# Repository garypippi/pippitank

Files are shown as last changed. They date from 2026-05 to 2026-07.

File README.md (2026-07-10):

# Pippitank

ラズパイ戦車制作プロジェクト

- 電源: 2S LiFe (タミヤ LF1100-6.6V)
- Raspberry Piでカメラ連携、リモート操作
- プッシュ型ソレノイドでBB弾発射

```
+----------+
| 2S LiFe  |
+----+-----+
     |
+----+-----------------+  UART  +-----------------------+
| pcb#pippitank-engine +--------+ pcb#pippitank-chassis |
+----+-----------------+        +----+--+-------+-------+
     |       |                       |  |       |
+-------+  +-------+      Dshot#2    |  |       | UART (Slip Ring)
| ESC#1 |  | ESC#2 |-----------------+  |       |
+----+--+  +-------+                    |    +----------------------+
     |                    Dshot#1       |    | pcb#pippitank-turret |
     +----------------------------------+    +----------------------+
                                                |
                                             ?? Planning... ??
```

## コマンド

### ビルド

```sh
cmake -S . -B build
cmake --build build
```

### RPi側

カメラストリーム配信。`--mode 1640:1232` はフル画角化のため（未指定だと中央クロップで約2.5倍ズームになる）:

```sh
rpicam-vid -t 0 --inline \
  --mode 1640:1232 \
  --width 640 --height 480 \
  --framerate 30 --listen -o tcp://0.0.0.0:8888
```

デーモン起動:

```sh
./build/src/pippitankd/pippitankd --listen 0.0.0.0:5000 --serial /dev/ttyS0
```

### ホスト側

操縦に使う入力デバイスの確認:

```sh
ls /dev/input/by-id
```

UI起動。`--log` は省略可（テレメトリCSVを記録する場合のみ）:

```sh
./build/src/pippitank-ui/pippitank-ui \
  --server pippitank:5000 \
  --video tcp://pippitank:8888 \
  --input /dev/input/event8 \
  --log logs/telemetry.csv
```

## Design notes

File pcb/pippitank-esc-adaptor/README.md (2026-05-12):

# ESCアダプタ基板

AM32 ESC(ARTERY AT32F421ベース、25A級) をシャーシに実装するためのアダプタ基板。
ESC × 2枚分で運用する。

## 目的

ESC本体を単独でシャーシに固定・配線するのが困難であるため、アダプタ基板に実装して機械・電気の一体化を図る。

## 全体構造

アダプタ基板の半月形状にし、内側2面でキャスタレーションする。
ESCを載せて実装。
各種コネクタ、バルクCの実装が容易になる想定。

追加パーツ:
定常5~15A、ピーク20~25A想定
ケーブルは18AWG

- コネクタ(電源): XT30PW-M
- コネクタ(出力): MR30PW-M
- コネクタ(信号): JST_XH_2PIN

銅箔はコスト、実用性の両面から、1oz。
両面にベタでstitching via。

電流容量検証(1oz 両面, 5mm幅相当):
- 連続容量 ≈ 14-16A(単層 8A の約2倍、2oz単層以上)
- 常用 5-15A、stall 瞬時 25A の要件に適合
- 発熱 0.16W@15A、温度上昇 10°C 未満

### バルクコンデンサ

ESCのBAT+/BAT-近傍に配置。
330μF、ESR性能重視。

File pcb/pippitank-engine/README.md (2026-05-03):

# pippitank-engine

2S Li-Po電源をESC#1, ESC#2, 車体システムへ分岐させる基板。

## 機能

- Pch-MOSFETで主電源ON/OFF
- MCUからNch-MOSFET経由でPch-MOSFETを制御
- 電圧監視
- 温度監視
- 電流監視

## 電圧監視地点

- 2S Li-Po電源 (VCC)
- 2S Li-Poセル#1 (バランスコネクタ経由)
- Pch-MOSFET直後

## 電流監視地点

各電源供給地点

- ESC#1
- ESC#2
- chassis/turret

## 温度測定地点

Pch-MOSFET近傍

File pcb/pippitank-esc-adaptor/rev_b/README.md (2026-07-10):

# pippitank-esc-adaptor rev_b

rev_a (2026-05-13 発注、2026-05-18 着) の実物検証で判明した課題を反映する次リビジョン。

**状態: 凍結 (2026-07-10)。rev_a が床走行まで実用に足りたため、着手トリガーは rev_a の故障・破損。**
本 README は着手時の申し送り集約として維持する。

## rev_a からの申し送り

### 1. Castellation スロット径拡大

rev_a は drill 0.6mm (JLCPCB 最小値) で設計、実物観察で側面銅露出が不足することが判明。

| Pad | 用途 | rev_a Size / Drill | rev_b 案 Size / Drill |
|---|---|---|---|
| 1, 2 | BAT+/BAT- | 3.0×2.5 / **0.6** | 3.0×2.5 / **1.0** |
| 3, 4, 5 | U/V/W 相出力 | 2.5×3.0 / **0.6** | 2.5×3.0 / **1.0** |
| 6, 7 | S/GND 信号 | 2.0×1.5 / **0.6** | 2.0×1.5 / **0.8** |

注: 寸法は JLCPCB castellation 仕様 (最小ピッチ・最小スロット径・推奨アスペクト比) を発注前に再確認すること。

### 2. QC 指標の変更

rev_a で「側面フィレット」を QC 指標としていたが、castellation の側面銅露出が
スロット内壁の半周のみであることが実物で確認された。形成不能なケースが標準となるため、
QC 指標として trivially に汚染される。

→ **rev_b 以降は「上面パッドのフィレット角度」を一次QC指標とする**。
   側面フィレットは形成されれば加点、未形成でも不合格にはしない。

### 3. U/V/W キャスタレーションのエッジカット中心ズレ

rev_a Known Issue より、U/V/W のエッジカットがスルーホール中心を通っていない。
rev_b で修正必須。

## 電流要件 (2026-06-26/27 床走行実測で確定)

rev_a 時代の仕様要求「常用 5-15A / ピーク 25A」は実測前の想定値だった。
床走行 Baseline (2S LiFe, 60:1 ウォーム, 超信地旋回・きびきび ramp 込み) の実測:

| 項目 | 実測値 |
|---|---|
| ESC 1台あたり DC 入力ピーク | **~3.5A** (きびきび ramp / 超信地旋回時) |
| 合計ピーク (2 ESC) | ~7A |
| 定常直進 | 1〜1.5A / ESC |
| 電圧サグ | 0.35V (系抵抗 ~78mΩ と整合、熱・電圧とも問題なし) |

**rev_b の設計電流は「各 ESC 10A」を採用** (engine rev_b 電流バジェット: 全体 30A = ESC 10A×2 + システム 10A と整合)。実測ピーク比で ~3倍のマージン。

### 注意 1: U/V/W 相電流は DC 入力より大きい

シャント実測は ESC の DC 入力側。相出力 (U/V/W) には duty < 100% で
DC 側より大きいトルク電流が流れる (一次近似 I_phase ≈ I_dc / duty)。
実測ピーク時 duty ~50% なら相側 ~7A 相当 → U/V/W パッドも 10A 基準で設計しておけば吸収できる。

### 注意 2: 個別ブランチの最悪ケース = 信地旋回は未測定

超信地旋回 (両履帯逆回転) はメイン電源パスの最悪ケースだが、片 ESC に旋回仕事が
集中する**信地旋回 (`l=±X, r=0`) は未取得**。片肺ピークが超信地の 1.5-1.6A/側を上回る
可能性はあるが、10A 設計に対して桁の余裕があるため設計ブロッカーではない。
詰める場合は信地旋回ログを別取りする。

## rev_a 許容電流試算 (参考、1oz Cu, IPC-2152 外層基準)

ボトルネックは上面パッド幅。バレル(半円メッキ)寄与は 2-3 割。

| 部位 | 連続容量 ΔT=10°C | 連続容量 ΔT=20°C |
|---|---|---|
| BAT± (3.0mm pad) | 11-12A | 15-17A |
| U/V/W (2.5mm pad) | 9-10A | 13-14A |

設計電流 10A に対し **rev_a 寸法のままでも ΔT=10°C 圏でほぼ収まる**。
したがって rev_b の drill 拡大 (0.6→1.0mm) の主目的は電流容量ではなく
**側面銅露出の改善 (はんだ濡れ性・QC 判定可能性) とマージン上積み**に整理される。
パッド拡大は必須ではなくなった (スペースと JLCPCB 制約次第の任意項目)。

## 設計タスク (TBD)

- [x] 電流要件の確定 (床走行実測 → 各 ESC 10A 基準、2026-07-10 反映)
- [ ] JLCPCB castellation 仕様再確認 (最小スロット径・ピッチ・縁部クリアランス)
- [ ] 上記寸法案で fp 修正・rev_a レイアウト引き継ぎ (パッド拡大は任意項目に格下げ)
- [ ] U/V/W エッジカット中心ズレ修正
- [ ] QC 指標の正式記載 (本 README 確定後、トップ README 反映)

## 注記

- 用途は室内床ホビー走行。屋外/泥/振動の脅威モデルは想定外
- 機械補強 (underfill, RTV 点付け, strain relief) は予防工程としては入れない。
  joint 浮きが出てから個別対処
- IPC-2152 ベースの試算は両面ベタGND+stitching via 構造で保守側、実機はやや余裕がある想定

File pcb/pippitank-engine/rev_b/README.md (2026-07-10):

改善

- FTDIモジュール対応
    - Arduino Unoのjtag2updi占有を脱する
- コネクタの最適化
    - 追記予定
- MCU駆動は3.3Vで統一

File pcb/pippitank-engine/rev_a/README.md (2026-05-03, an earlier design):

**Known Issues**

1. バランスコネクタのGND,8.4Vが逆
    - JST_XH_3PIN Verticalを逆で実装すること
2. Nch-MOSFETのソースが浮いている
    - SWはON状態で固定すること

## 主要パーツ

- MCU: ATtiny1604
- Pch-MOSFET: TJ60S04M3L
- 電流測定用アンプ: LT6106CS5

## 設計根拠

電力想定

- 各ESCはMAX30A
- システムはMAX5A

## コネクタ

- XT60PW-M: 2S Li-Po
- XT60PW-M: ESC#1
- XT60PW-M: ESC#2
- XT30PW-M: システム#1
- XT30PW-M: システム#2
- JST_XH_3PIN: 2S Li-Po バランスコネクタ
- JST_XH_3PIN: UPDI
- JST_XH_4PIN: UART

## 電流測定 (ESC)

シャント抵抗は1W7mΩ ±5%を調達
並列数は4、 上限30Aとして

- 各抵抗の電流: 7.5A
- 各抵抗の電力: 0.394W
- 電圧降下@30A: 52.5mV
- 必要利得    : 20.95
- 測定誤差@30A: ±0.2A
- 測定誤差@10A: ±2.0%
- 測定誤差@05A: ±4.0%

ADC基準電圧は、精度を優先し1.1Vを使用する。
必要利得は

20.95 = 1100 / 52.5

利得は`ROUT/RIN`で設定する。
RINの範囲にはLT6106内部電流の制約がある。

> 内部電流の上限は1mA、30A時のセンス電圧52.5mVを流すには
> RIN ≥ 52.5mV / 1mA = 52.5Ω
> が必要。
> データシート条件から
> RIN ≤ 500Ω

よって

52.5Ω < RIN < 500Ω

- RIN=240Ω
- ROUT=4.7kΩ (Av≈19.58)
- 出力@30A=1.028V
- 実効FS≈32.1A

出力フィルタは2段LPF構成にする。

- 1段目(LT6106付近): ROUT(4.7kΩ) × COUT1(0.1μF) ≈ 338Hz
    - PWMノイズ(16〜32kHz)を発生源で大幅減衰（-33dB以上）
    - フィルタ後の出力インピーダンスが高周波で低くなり、配線のアンテナ化を抑制
- 2段目(ADC付近): Rs(100Ω) × COUT2(10nF) ≈ 160kHz
    - 長配線で新規に拾ったHFスパイク（FETスイッチング過渡、RF誘導）を叩き落とす
    - ATtiny1604のSAR ADC S/Hキャパへのローカル電荷供給も兼用

```
┌───────┬───────┬──────────────────────────────────────┐
│ 素子  │  値   │                 用途                 │
├───────┼───────┼──────────────────────────────────────┤
│ RIN   │ 240Ω  │ 入力抵抗                             │
├───────┼───────┼──────────────────────────────────────┤
│ ROUT  │ 4.7kΩ │ 出力抵抗（利得設定 兼 1段目LPFのR）  │
├───────┼───────┼──────────────────────────────────────┤
│ COUT1 │ 0.1μF │ ROUT並列、1段目LPFのC（LT6106直近）  │
├───────┼───────┼──────────────────────────────────────┤
│ Rs    │ 100Ω  │ 2段目LPFの直列R（配線途中〜ADC直前） │
├───────┼───────┼──────────────────────────────────────┤
│ COUT2 │ 10nF  │ 2段目LPFのC（ADC直近）               │
└───────┴───────┴──────────────────────────────────────┘
```

**実装時はケルビン接続**

## 電流測定 (システム)

車体、砲塔への電流測定。
負荷はRPi Zero W、RPi Camera、サーボx2、プッシュ型ソレノイド、各MCU

シャント抵抗は1W40mΩ ±1%を調達
並列数は2、 上限5Aとして

- 各抵抗の電流: 2.5A
- 各抵抗の電力: 0.25W (定格50%デレーティング)
- 電圧降下@5A: 100mV
- 必要利得    : 11.0
- 測定誤差@5A: ±1.0%
- 測定誤差@1A: ±5.0%

ADC基準電圧は、精度を優先し1.1Vを使用する。
必要利得は

11.0 = 1100 / 100

- RIN=240Ω
- ROUT=2.4kΩ (Av≈10.0) ※ 2.4kΩは調達しやすい

出力フィルタは2段LPF構成にする。

- 1段目(LT6106付近): ROUT(2.4kΩ) × COUT1(0.1μF) ≈ 663Hz
- 2段目(ADC付近): Rs(100Ω) × COUT2(10nF) ≈ 160kHz

```
┌───────┬───────┬──────────────────────────────────────┐
│ 素子  │  値   │                 用途                 │
├───────┼───────┼──────────────────────────────────────┤
│ RIN   │ 240Ω  │ 入力抵抗                             │
├───────┼───────┼──────────────────────────────────────┤
│ ROUT  │ 2.4kΩ │ 出力抵抗（利得設定 兼 1段目LPFのR）  │
├───────┼───────┼──────────────────────────────────────┤
│ COUT1 │ 0.1μF │ ROUT並列、1段目LPFのC（LT6106直近）  │
├───────┼───────┼──────────────────────────────────────┤
│ Rs    │ 100Ω  │ 2段目LPFの直列R（配線途中〜ADC直前） │
├───────┼───────┼──────────────────────────────────────┤
│ COUT2 │ 10nF  │ 2段目LPFのC（ADC直近）               │
└───────┴───────┴──────────────────────────────────────┘
```

**実装時はケルビン接続**

## 電圧測定

測定地点

1. BATバランス端子: セル#1
2. BAT(+) - BAT(-): 2 - 1 = セル#2電圧
3. post-MOSFETノード - BAT(-): ESC両系統への給電電圧 (Pch-MOSFET ON確認 + 電圧降下モニタ兼用)

抵抗分圧について、精度優先で内蔵基準電圧1.1Vを使用する
MAX8.4として

- (R1+R2)/R2 = 8.4 / 1.1 = 7.64
- R1/R2 = 6.64

R1 = 67kΩ (47kΩ + 20kΩ)
R2 = 10kΩ (8.4V時 1.091V、6.0V時 0.779V)

MAX4.2の場合は R1=47kΩ にすれば良い(4.2V時 0.737V)

LT6106の電流測定と同じく、2段LPF構成で配置する

```
Vin ── R1 ──┬──[配線]── Rs ──┬── ATtiny ADC
            │                │
            R2               C2(10nF)
            │                │
            ├── C1(0.1μF)    GND
            │
           GND
```

- R1, R2, C1 は信号源側に密集させる
  - R2 をMCU側に離すと配線区間が R1=67kΩ の高インピーダンスになり、ノイズを盛大に拾う
  - R1||R2 = 8.7kΩ を信号源側で確立し、低インピーダンス信号を配線に乗せる
- Rs（100Ω）は配線途中〜ADC直前（LT6106と同規格）
  - 2段目LPFの直列R、ADC入力保護
- C2=10nF はADC直近（LT6106のCOUT2と共用規格）
  - 配線で拾ったHFノイズをADC直前でシャント
  - ATtiny1604 SAR ADC のS/Hキャパ充電にも寄与

```
┌───────┬──────────┬──────────────────────────────────────┐
│ 素子  │   値     │               用途                   │
├───────┼──────────┼──────────────────────────────────────┤
│ R1    │ 67kΩ等   │ 分圧上段（信号源側）                 │
├───────┼──────────┼──────────────────────────────────────┤
│ R2    │ 10kΩ     │ 分圧下段（信号源側、R1とセット）     │
├───────┼──────────┼──────────────────────────────────────┤
│ C1    │ 0.1μF    │ R2並列、1段目LPF（信号源側）         │
├───────┼──────────┼──────────────────────────────────────┤
│ Rs    │ 100Ω     │ 2段目LPFの直列R（電流系と共用規格）  │
├───────┼──────────┼──────────────────────────────────────┤
│ C2    │ 10nF     │ 2段目LPF（ADC直近、電流系と共用規格）│
└───────┴──────────┴──────────────────────────────────────┘
```

## 基板温度測定

Pch-MOSFET および シャント抵抗の発熱監視用に NTCサーミスタを1点実装する。

- サーミスタ: NTC 47kΩ ±5% B=4050K ±3% (TDK NTH5G20P40B473J、2012)
- プルアップ: 47kΩ ±5% (NTC R25と対称にして25°C付近の感度最大化、±5%は調達制約・表示用途なら実用上問題なし)
- フィルタ: 2段LPF構成
- ADC参照: VDD(5V) ※この1chのみ、他chは1.1V内部参照のまま

```
VCC(5V) ── R_pu 47kΩ ──┬──[配線]── Rs ──┬── ATtiny ADC (PA7)
                       │                │
                       NTC 47kΩ         C2 (10nF)
                       │                │
                       ├── C1 (0.1μF)   GND
                       │
                       GND
```

温度 vs ADCコード (VDD=5V, 10bit, B=4050K):

```
┌──────┬─────────┬────────┬─────────┐
│ 温度 │ NTC抵抗 │  電圧  │ ADCコード │
├──────┼─────────┼────────┼─────────┤
│ 0°C  │ 163kΩ   │ 3.88V  │  795    │
│ 25°C │ 47kΩ    │ 2.50V  │  512    │
│ 60°C │ 11.3kΩ  │ 0.97V  │  198    │
│ 85°C │ 4.84kΩ  │ 0.47V  │   96    │
│100°C │ 3.06kΩ  │ 0.31V  │   63    │
└──────┴─────────┴────────┴─────────┘
```

Pch-MOSFET裏面の銅箔ベタに密着させ、シャント抵抗発熱も熱結合で捕捉する。
シャットダウン閾値はマージンを取り ADCコード 110 (公称 82°C) 付近で発動、
最悪ケース (B+3%, R25+5%) でも実温度 85°C を超える前に遮断される想定とする。

```
┌───────┬──────────┬─────────────────────────────────────┐
│ 素子  │   値     │               用途                  │
├───────┼──────────┼─────────────────────────────────────┤
│ R_pu  │ 47kΩ ±5% │ プルアップ（信号源側）              │
├───────┼──────────┼─────────────────────────────────────┤
│ NTC   │ 47kΩ     │ NTH5G20P40B473J（信号源側）         │
├───────┼──────────┼─────────────────────────────────────┤
│ C1    │ 0.1μF    │ 1段目LPF（信号源側、NTC並列）       │
├───────┼──────────┼─────────────────────────────────────┤
│ Rs    │ 100Ω     │ 2段目LPFの直列R（全系統共用規格）   │
├───────┼──────────┼─────────────────────────────────────┤
│ C2    │ 10nF     │ 2段目LPF（ADC直近、全系統共用規格） │
└───────┴──────────┴─────────────────────────────────────┘
```

## ATtiny1604

ATtiny1604の消費電力は小さいので、BAT接続時は常に稼働させる

```
BAT(+) ---+---------- (VIN) AP7375 (VOUT) -+--- (A)▷|(K) --- VCC rail --- ATtiny1604
          |                  |             |         D2                   UPDI 5V pin
          | CIN=1μF          |             |
          |                  |             | COUT=10μF
BAT(-) ---+------------------+-------------+
```

- LDO: AP7375(5V300mA)
- 内蔵オシレータ使用
- UPDI引き出し
- 逆流防止ショットキー D2

BAT未接続状態でもArduino Uno経由でUPDI書き込みできるよう、AP7375出力とVCC rail間にショットキーダイオードを挿入する。

- 型番: RB160M-30TR (ROHM, 30V 1A)
- パッケージ: SOD-123F (PMDS、フラットリード)
- VF: 0.43V @ 1A、実動作の~10mA負荷では ~0.2V
- VCC rail電圧: 5.0V - 0.2V ≈ 4.8V（ATtiny動作範囲1.8-5.5V内）

```
AP7375 --+-- (A)▷|(K) ----+----- ATtiny VCC (pin 1)
         |      D2         |
         |                 +--- UPDI header 5V pin
         C2=10μF           |
         |                 C_bypass=0.1μF
        GND               GND
```

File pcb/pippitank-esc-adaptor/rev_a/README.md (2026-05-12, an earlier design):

**Known Issues**

1. U/V/Wのキャスタレーションでエッジカットがスルーホールの中心を通っていない

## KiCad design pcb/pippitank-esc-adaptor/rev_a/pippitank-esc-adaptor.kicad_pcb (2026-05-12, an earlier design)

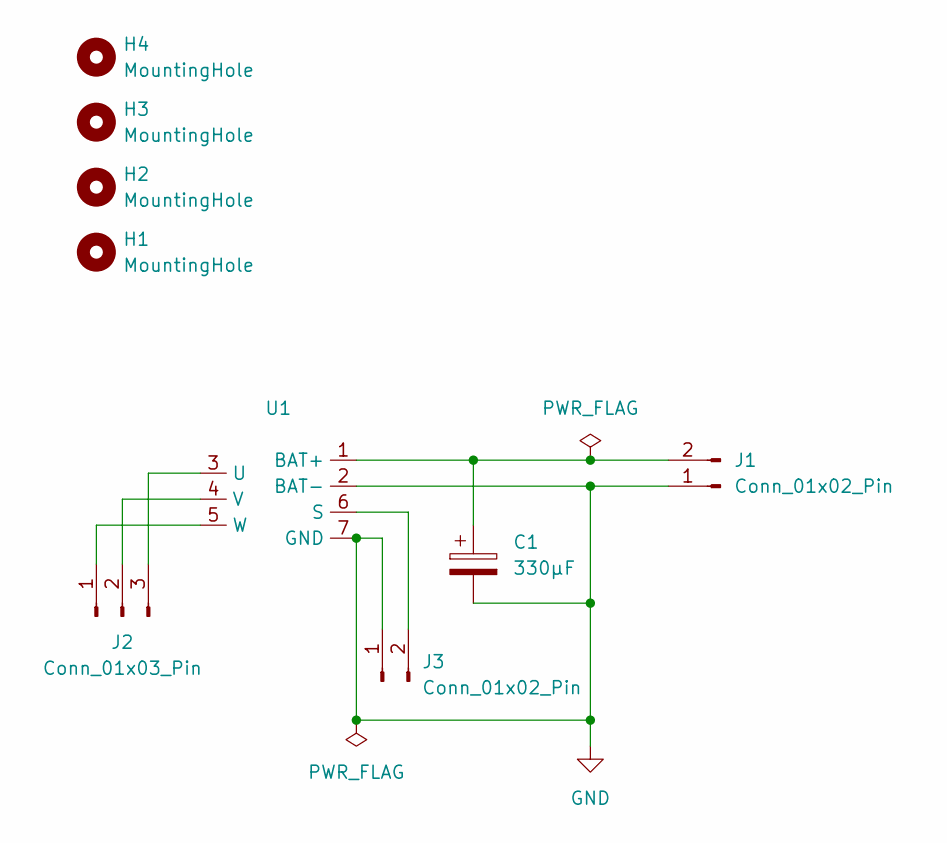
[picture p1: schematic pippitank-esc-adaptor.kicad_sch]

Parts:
C1: 330μF; CP_Radial_D10.0mm_P5.00mm
H1, H2, H3, H4: MountingHole; MountingHole_3.2mm_M3
J1: Conn_01x02_Pin; AMASS_XT30PW-M_1x02_P2.50mm_Horizontal
J2: Conn_01x03_Pin; AMASS_MR30PW-M_1x03_P3.50mm_Horizontal
J3: Conn_01x02_Pin; JST_XH_B2B-XH-A_1x02_P2.50mm_Vertical
U1: NOBRAND_ESC_ADAPTOR

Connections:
GND: C1.2, J1.1, J3.1, U1.2 (BAT-), U1.7 (GND)
unnamed: C1.1, J1.2, U1.1 (BAT+)
unnamed: J2.1, U1.5 (W)
unnamed: J2.2, U1.4 (V)
unnamed: J2.3, U1.3 (U)
unnamed: J3.2, U1.6 (S)

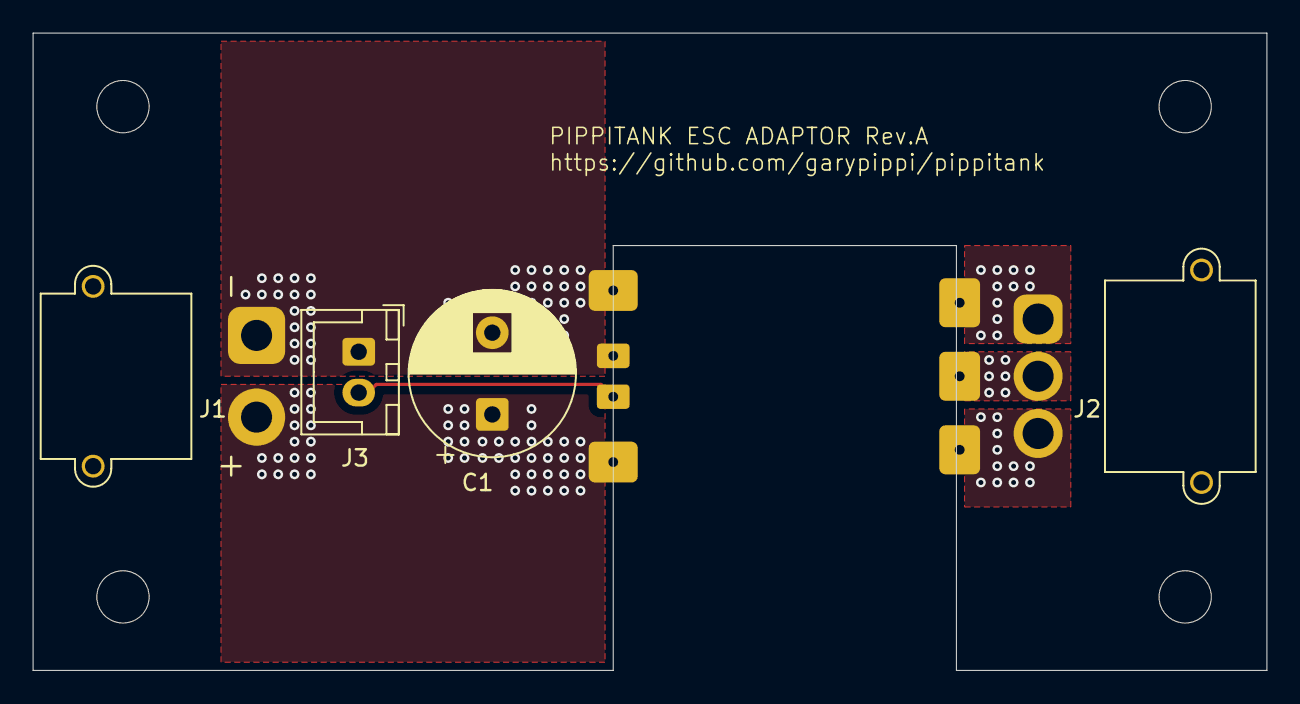
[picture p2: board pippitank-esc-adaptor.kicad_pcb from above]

Board: 2 copper layers, 75.5 x 39.0 mm, 9 parts (1 on the bottom side), 6 nets.

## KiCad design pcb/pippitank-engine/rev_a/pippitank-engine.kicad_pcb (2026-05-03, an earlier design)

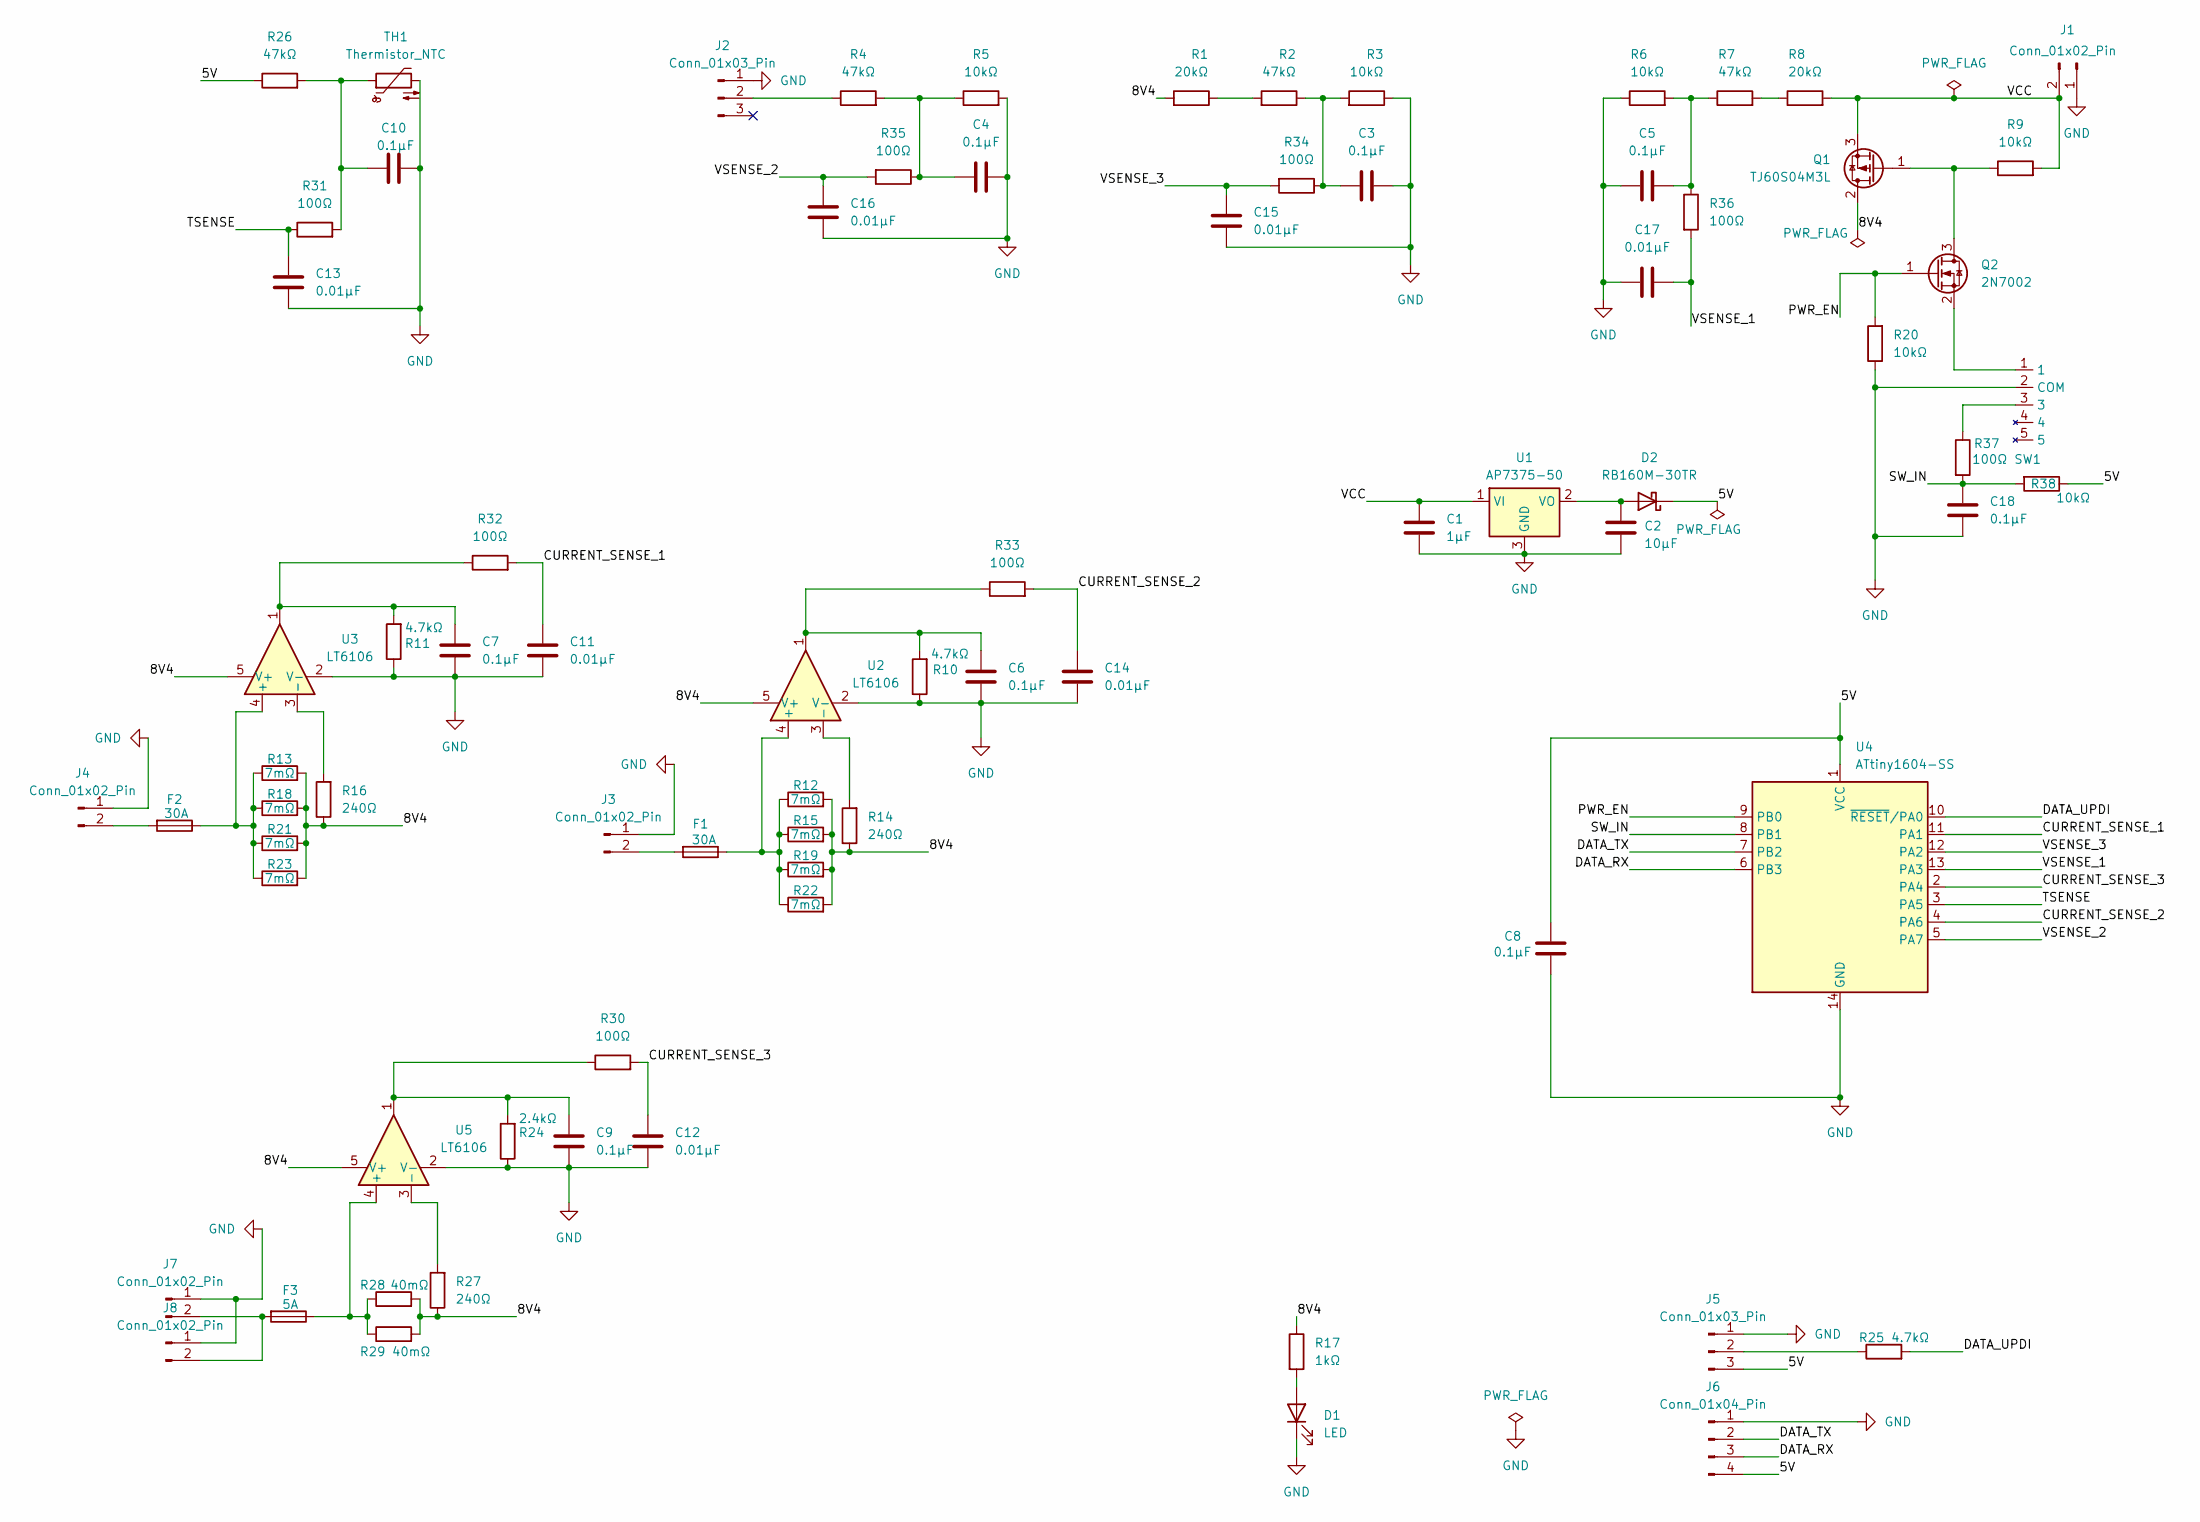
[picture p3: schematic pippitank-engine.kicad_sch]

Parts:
C1: 1μF; R_0603_1608Metric_Pad0.98x0.95mm_HandSolder
C2: 10μF; R_0805_2012Metric_Pad1.20x1.40mm_HandSolder
C3, C4, C5, C6, C7, C8, C9, C10, C18: 0.1μF; R_0603_1608Metric_Pad0.98x0.95mm_HandSolder
C11, C12, C13, C14, C15, C16, C17: 0.01μF; R_0603_1608Metric_Pad0.98x0.95mm_HandSolder
D1: LED; LED_0603_1608Metric_Pad1.05x0.95mm_HandSolder
D2: RB160M-30TR; D_SOD-123F
F1, F2: 30A; Keystone_3557_15
F3: 5A; Keystone_3557_15
J1, J3, J4: Conn_01x02_Pin; AMASS_XT60PW-M_1x02_P7.20mm_Horizontal
J2: Conn_01x03_Pin; JST_XH_S3B-XH-A_1x03_P2.50mm_Horizontal
J5: Conn_01x03_Pin; JST_XH_B3B-XH-A_1x03_P2.50mm_Vertical
J6: Conn_01x04_Pin; JST_XH_S4B-XH-A_1x04_P2.50mm_Horizontal
J7, J8: Conn_01x02_Pin; AMASS_XT30PW-M_1x02_P2.50mm_Horizontal
Q1: TJ60S04M3L; TO-252-3_TabPin2
Q2: 2N7002; SOT-23
R1, R8: 20kΩ; R_0603_1608Metric_Pad0.98x0.95mm_HandSolder
R2, R4, R7, R26: 47kΩ; R_0603_1608Metric_Pad0.98x0.95mm_HandSolder
R3, R5, R6, R9, R20, R38: 10kΩ; R_0603_1608Metric_Pad0.98x0.95mm_HandSolder
R10, R11, R25: 4.7kΩ; R_0603_1608Metric_Pad0.98x0.95mm_HandSolder
R12, R13, R15, R18, R19, R21, R22, R23: 7mΩ; R_2512_6332Metric
R14, R16, R27: 240Ω; R_0603_1608Metric_Pad0.98x0.95mm_HandSolder
R17: 1kΩ; R_0603_1608Metric_Pad0.98x0.95mm_HandSolder
R24: 2.4kΩ; R_0603_1608Metric_Pad0.98x0.95mm_HandSolder
R28, R29: 40mΩ; R_2512_6332Metric
R30, R31, R32, R33, R34, R35, R36, R37: 100Ω; R_0603_1608Metric_Pad0.98x0.95mm_HandSolder
SW1: SSAJ120100
TH1: Thermistor_NTC; R_0805_2012Metric_Pad1.20x1.40mm_HandSolder
U1: AP7375-50; SOT-23_Handsoldering
U2, U3, U5: LT6106; SOT-23-5_HandSoldering
U4: ATtiny1604-SS; SOIC-14_3.9x8.7mm_P1.27mm

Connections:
/5V: C8.2, D2.1 (K), J5.3, J6.4, R26.1, R38.1, U4.1 (VCC)
/8V4: Q1.2 (D), R1.2, R12.2, R13.2, R14.1, R15.2, R16.1, R17.1, R18.2, R19.2, R21.2, R22.2, R23.2, R27.1, R28.2, R29.2, U2.5 (V+), U3.5 (V+), U5.5 (V+)
/CURRENT_SENSE_1: C11.1, R32.2, U4.11 (PA1)
/CURRENT_SENSE_2: C14.1, R33.2, U4.4 (PA6)
/CURRENT_SENSE_3: C12.1, R30.2, U4.2 (PA4)
/DATA_RX: J6.3, U4.6 (PB3)
/DATA_TX: J6.2, U4.7 (PB2)
/DATA_UPDI: R25.2, U4.10 (~RESET/PA0)
/PWR_EN: Q2.1 (G), R20.2, U4.9 (PB0)
/SW_IN: C18.2, R37.2, R38.2, U4.8 (PB1)
/TSENSE: C13.1, R31.1, U4.3 (PA5)
/VCC: C1.1, J1.2, Q1.3 (S), R8.2, R9.2, U1.1 (VI)
/VSENSE_1: C17.1, R36.2, U4.13 (PA3)
/VSENSE_2: C16.2, R35.2, U4.5 (PA7)
/VSENSE_3: C15.2, R34.2, U4.12 (PA2)
GND: C1.2, C2.2, C3.2, C4.2, C5.2, C6.2, C7.2, C8.1, C9.2, C10.1, C11.2, C12.2, C13.2, C14.2, C15.1, C16.1, C17.2, C18.1, D1.1 (K), J1.1, J2.1, J3.1, J4.1, J5.1, J6.1, J7.1, J8.1, R3.1, R5.2, R6.1, R10.1, R11.1, R20.1, R24.1, SW1.2 (COM), TH1.2, U1.3 (GND), U2.2 (V-), U3.2 (V-), U4.14 (GND), U5.2 (V-)
unnamed: C3.1, R2.1, R3.2, R34.1
unnamed: C4.1, R4.2, R5.1, R35.1
unnamed: C5.1, R6.2, R7.1, R36.1
unnamed: C6.1, R10.2, R33.1, U2.1
unnamed: C7.1, R11.2, R32.1, U3.1
unnamed: C9.1, R24.2, R30.1, U5.1
unnamed: C10.2, R26.2, R31.2, TH1.1
unnamed: D1.2 (A), R17.2
unnamed: C2.1, D2.2 (A), U1.2 (VO)
unnamed: J2.2, R4.1
unnamed: F1.2, J3.2
unnamed: F2.2, J4.2
unnamed: J5.2, R25.1
unnamed: F3.2, J7.2, J8.2
unnamed: Q1.1 (G), Q2.3 (D), R9.1
unnamed: Q2.2 (S), SW1.1
unnamed: R1.1, R2.2
unnamed: R7.2, R8.1
unnamed: R37.1, SW1.3
unnamed: F1.1, R12.1, R15.1, R19.1, R22.1, U2.4 (+)
unnamed: R14.2, U2.3 (-)
unnamed: F2.1, R13.1, R18.1, R21.1, R23.1, U3.4 (+)
unnamed: R16.2, U3.3 (-)
unnamed: F3.1, R28.1, R29.1, U5.4 (+)
unnamed: R27.2, U5.3 (-)

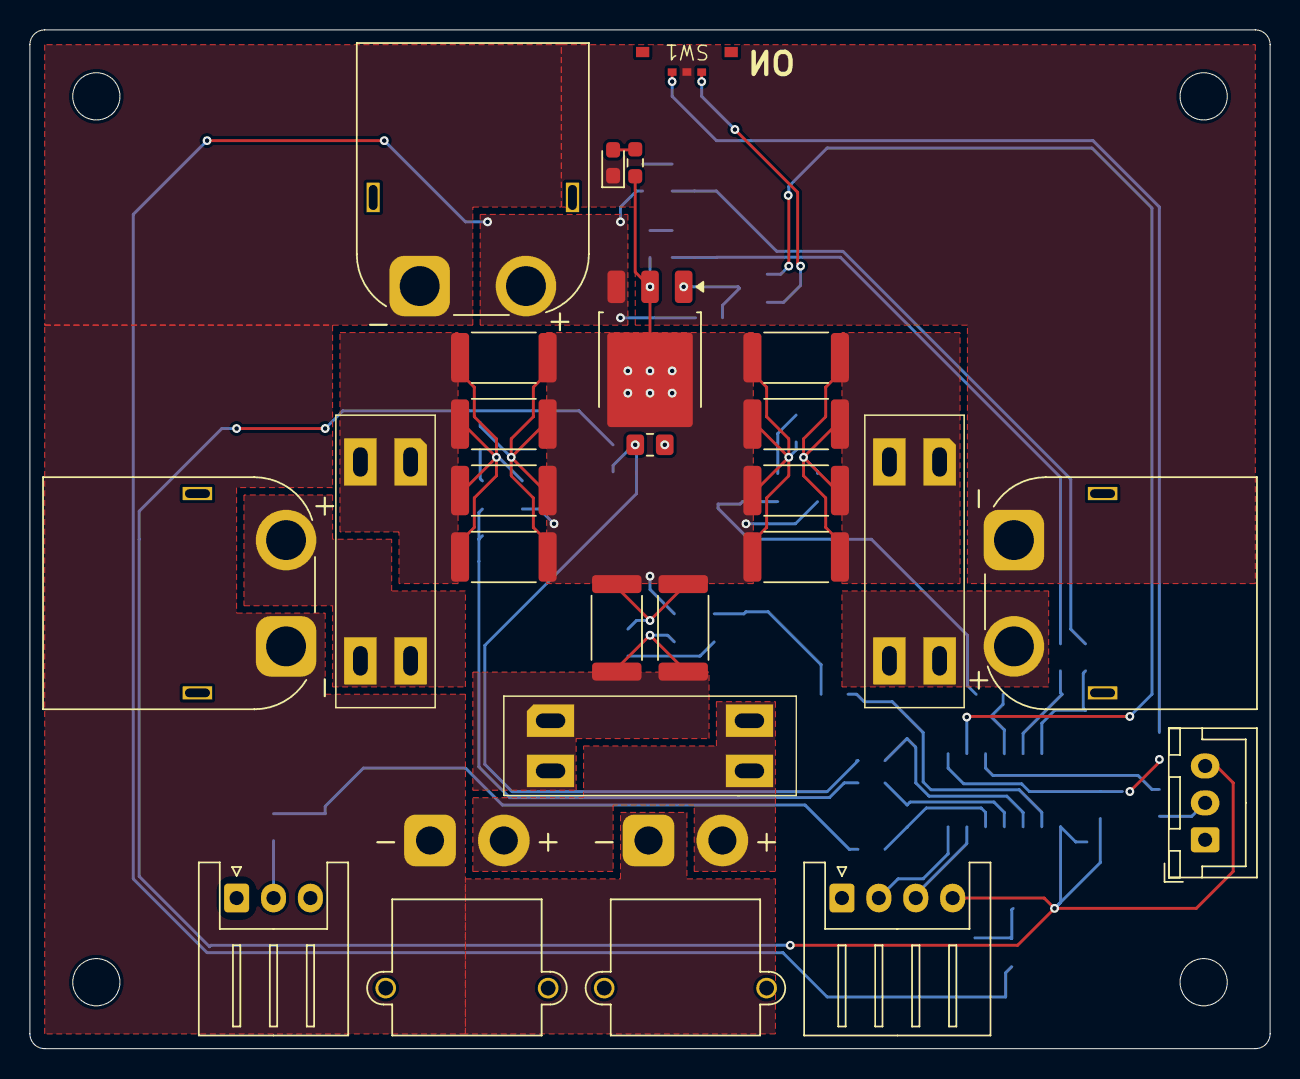
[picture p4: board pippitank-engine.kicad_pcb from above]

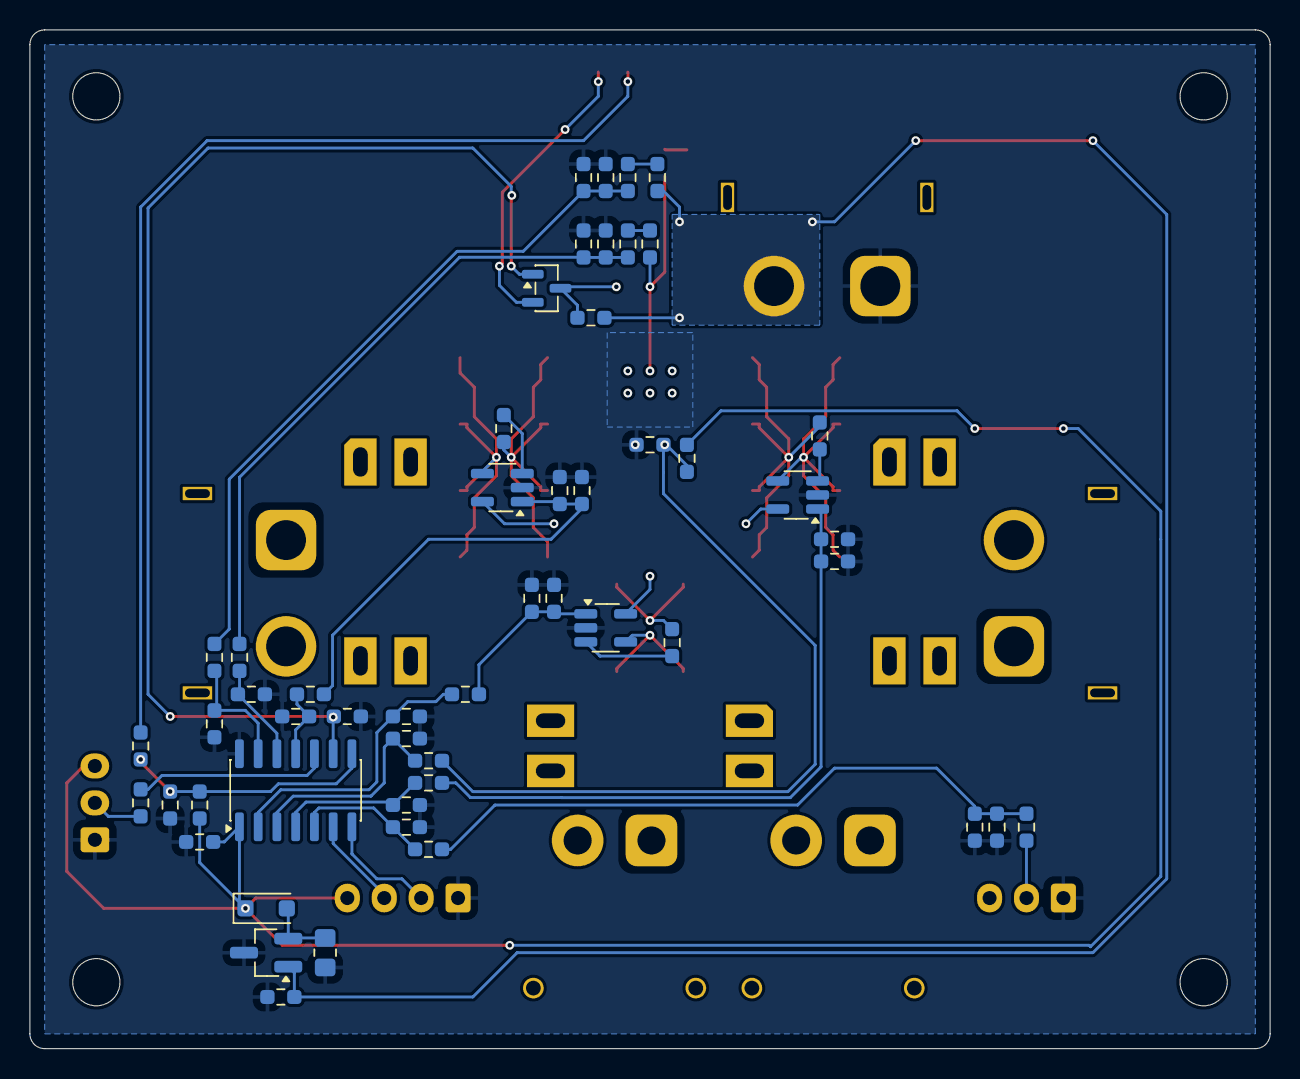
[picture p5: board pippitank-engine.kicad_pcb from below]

Board: 2 copper layers, 84.0 x 69.0 mm, 78 parts (52 on the bottom side), 41 nets.

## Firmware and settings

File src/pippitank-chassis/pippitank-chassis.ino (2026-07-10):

//const uint32_t BAUDRATE = 19200;
//uint32_t hb_last_ms = 0;
//uint32_t hb_state   = false;
//
//void setup() {
//  // RPi
//  Serial1.setTX(0);
//  Serial1.setRX(1);
//  Serial1.begin(BAUDRATE);
//
//  // pippitank-engine
//  Serial2.setTX(4);
//  Serial2.setRX(5);
//  Serial2.begin(BAUDRATE);
//  //Serial1.begin(BAUDRATE); // RPi
//  //Serial2.begin(BAUDRATE); // pippitank-engine
//  pinMode(LED_BUILTIN, OUTPUT);
//}
//
//void loop() {
//  // Pass through pippitank-engine's telemetory
//  if (Serial2.available()) {
//    Serial1.write(Serial2.read());
//  }
//
//  // Heart beat
//  uint32_t now = millis();
//  if (now - hb_last_ms >= 500) {
//    hb_last_ms = now;
//    hb_state = !hb_state;
//    digitalWrite(LED_BUILTIN, hb_state);
//  }
//}


#include <Servo.h>
#include "./protocol.h"

const uint8_t PIN_ESC_1 = 6;   // 適宜
const uint8_t PIN_ESC_2 = 7;

const int PWM_MIN  = 1000;
const int PWM_MAX  = 2000;
const int PWM_IDLE = 1500;

Servo esc_l;
Servo esc_r;

const uint32_t BAUDRATE = 19200;
const uint8_t  LED_PIN  = LED_BUILTIN;

uint32_t led_last_ms  = 0;
uint32_t stat_last_ms = 0;
bool     led_state    = false;

uint32_t engine_frames_ok  = 0;
uint32_t engine_frames_err = 0;

struct pt_rx rx_engine;
struct pt_rx rx_cmd;

const uint32_t ESC_ARM_DELAY_MS = 2000;
bool esc_armed = false;

const uint32_t CHASSIS_TX_PERIOD_MS = 33;   // 30Hz
uint32_t chassis_tx_last_ms = 0;

volatile int16_t  target_throttle_l = 0;
volatile int16_t  target_throttle_r = 0;
volatile uint32_t last_cmd_ms       = 0;

const uint32_t ESC_UPDATE_MS = 20;   // 50Hz
const uint32_t CMD_TIMEOUT_MS = 500;
uint32_t esc_update_last = 0;

//void handle_cmd(const struct pt_rx *rx) {
//    const struct pt_header *hdr = (const struct pt_header *)rx->buf;
//    if (hdr->typ == PT_TYP_CMD_DRIVE
//        && hdr->len == sizeof(struct pt_payload_cmd_drive)) {
//        const struct pt_frame_cmd_drive *f = (const struct pt_frame_cmd_drive *)rx->buf;
//        target_throttle_l = f->payload.throttle_l;
//        target_throttle_r = f->payload.throttle_r;
//        last_cmd_ms = millis();
//          Serial.printf("CMD_DRIVE L=%d R=%d (count=%u)\n",
//                last_throttle_l, last_throttle_r, cmd_count);
//    }
//}
uint32_t cmd_count = 0;
//int16_t  last_throttle_l = 0;
//int16_t  last_throttle_r = 0;
void handle_cmd(const struct pt_rx *rx) {
  const struct pt_header *hdr = (const struct pt_header *)rx->buf;

  if (hdr->typ == PT_TYP_CMD_DRIVE
      && hdr->len == sizeof(struct pt_payload_cmd_drive))
  {
      const struct pt_frame_cmd_drive *f = (const struct pt_frame_cmd_drive *)rx->buf;
      target_throttle_l = f->payload.throttle_l;
      target_throttle_r = f->payload.throttle_r;
      last_cmd_ms = millis();
      cmd_count++;
      Serial.printf("CMD_DRIVE L=%d R=%d (count=%u)\n",
                    target_throttle_l, target_throttle_r, cmd_count);
  }
}

void send_chassis_telemetry() {
     struct pt_frame_chassis frame;
     frame.header.syn = PT_SYNC;
     frame.header.src = PT_SRC_CHASSIS;
     frame.header.typ = PT_TYP_TELEMETORY;
     frame.header.len = sizeof(frame.payload);

     frame.payload.uptime_ms = millis();
     frame.payload.engine_frames_ok = engine_frames_ok;
     frame.payload.engine_frames_dropped = 0;   // 実装は後で
     frame.payload.flags = 0;

     frame.crc = pt_crc8(&frame.header.src, 3 + sizeof(frame.payload));

     Serial1.write((const uint8_t*)&frame, sizeof(frame));
}

int throttle_to_pwm(int16_t t) {
      if (t > 1000)  t = 1000;
      if (t < -1000) t = -1000;
      return PWM_IDLE + t / 2;   // -1000 → 1000us, 0 → 1500us, +1000 → 2000us
}

void setup() {
    Serial.begin(115200);

    Serial1.setTX(0);
    Serial1.setRX(1);
    Serial1.begin(BAUDRATE);

    Serial2.setTX(4);
    Serial2.setRX(5);
    Serial2.begin(BAUDRATE);

    pinMode(LED_PIN, OUTPUT);

    esc_l.attach(PIN_ESC_1, PWM_MIN, PWM_MAX);
    esc_r.attach(PIN_ESC_2, PWM_MIN, PWM_MAX);
    esc_l.writeMicroseconds(PWM_IDLE);
    esc_r.writeMicroseconds(PWM_IDLE);

    pt_rx_init(&rx_engine);
}

void loop() {
    // engine からの受信 → state machine へ
    while (Serial2.available()) {
        uint8_t b = Serial2.read();
        pt_rx_feed(&rx_engine, b);

        if (rx_engine.done == 1) {
            rx_engine.done = 0;
            // フレーム完成 → そのまま RPi へ
            // 全長 = sizeof(pt_header) + payload_len + 1(CRC)
            size_t frame_len = sizeof(struct pt_header) + rx_engine.buf[3] + 1;
            Serial1.write(rx_engine.buf, frame_len);
            engine_frames_ok++;
        }
        // CRC エラーは pt_rx_feed 内で done=0 のまま捨てられる
        // → ここでは err カウントできない、要なら state machine 側に追加
    }

    while (Serial1.available()) {
        uint8_t b = Serial1.read();
        pt_rx_feed(&rx_cmd, b);
        if (rx_cmd.done == 1) {
            rx_cmd.done = 0;
            handle_cmd(&rx_cmd);
        }
    }

    uint32_t now = millis();

    // chassis 自前テレメトリ
    if (now - chassis_tx_last_ms >= CHASSIS_TX_PERIOD_MS) {
        chassis_tx_last_ms = now;
        send_chassis_telemetry();
    }

    if (!esc_armed && now >= ESC_ARM_DELAY_MS) {
        esc_armed = true;
    }

    if (now - last_cmd_ms > CMD_TIMEOUT_MS) {
      target_throttle_l = 0;
      target_throttle_r = 0;
    }

    if (now - esc_update_last >= ESC_UPDATE_MS) {
         esc_update_last = now;
         if (esc_armed) {
             Serial.printf("ESC %d %d \n", throttle_to_pwm(target_throttle_l), throttle_to_pwm(target_throttle_r));
             esc_l.writeMicroseconds(throttle_to_pwm(target_throttle_l));
             esc_r.writeMicroseconds(throttle_to_pwm(target_throttle_r));
         }
    }

    // ハートビート LED
    if (now - led_last_ms >= 500) {
        led_last_ms = now;
        led_state = !led_state;
        digitalWrite(LED_PIN, led_state);
    }
    // 統計
    if (now - stat_last_ms >= 1000) {
        stat_last_ms = now;
        Serial.printf("engine_ok=%u\n", engine_frames_ok);
    }
}

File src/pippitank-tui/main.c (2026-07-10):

#include "../protocol.h"
#include "./conv.h"
#include <arpa/inet.h>
#include <fcntl.h>
#include <getopt.h>
#include <linux/input.h>
#include <ncurses.h>
#include <netinet/in.h>
#include <poll.h>
#include <signal.h>
#include <stdio.h>
#include <stdlib.h>
#include <sys/socket.h>
#include <sys/timerfd.h>
#include <sys/un.h>
#include <unistd.h>

#define BUFFER_SIZE 128

// enum pt_rx_state {
//     WAIT_SYNC,
//     READ_HEADER,
//     READ_PAYLOAD,
//     READ_CRC
// };
//
// struct pt_rx_engine {
//     enum pt_rx_state state;
//     uint8_t buf[sizeof(struct pt_frame_engine) + 1];
//     uint16_t pos;
//     uint16_t len;
//     int done;
// };

void cleanup_ncurses(void) { endwin(); }

void on_sigint(int sig) {
  (void)sig;
  exit(0);
}

// y, x: 描画開始位置、width: バー幅(文字数)、value: 値、max: 最大値
void draw_bar(int y, int x, int width, float value, float max) {
  if (value < 0)
    value = 0;
  if (value > max)
    value = max;
  int filled = (int)(value * width / max);

  mvaddch(y, x, '[');
  for (int i = 0; i < width; i++) {
    mvaddch(y, x + 1 + i, i < filled ? '#' : '.');
  }
  mvaddch(y, x + 1 + width, ']');
}

// void pt_rx_engine_feed(struct pt_rx_engine* engine, uint8_t data)
//{
//     switch (engine->state)
//     {
//         case WAIT_SYNC:
//             if (data == PT_SYNC)
//             {
//                 engine->state = READ_HEADER;
//                 engine->buf[engine->pos++] = data;
//                 engine->len = sizeof(struct pt_header) - 1;
//             }
//             break;
//         case READ_HEADER:
//             engine->buf[engine->pos++] = data;
//             engine->len--;
//
//             if (engine->len == 0)
//             {
//                 engine->state = READ_PAYLOAD;
//                 engine->len = sizeof(struct pt_payload_engine);
//                 if (engine->buf[3] != sizeof(struct pt_payload_engine))
//                 {
//                     fprintf(stderr, "[ERROR] pt_header len mismatch.\n");
//                     engine->state = WAIT_SYNC;
//                     engine->pos = 0;
//                 }
//             }
//             break;
//         case READ_PAYLOAD:
//             engine->buf[engine->pos++] = data;
//             engine->len--;
//
//             if (engine->len == 0)
//             {
//                 engine->state = READ_CRC;
//             }
//             break;
//         case READ_CRC:
//             if (pt_crc8(engine->buf + 1, 3 + sizeof(struct
//             pt_payload_engine)) != data)
//             {
//                 fprintf(stderr, "[ERROR] CRC error\n");
//             }
//             else
//             {
//                 engine->done = 1;
//             }
//             engine->buf[engine->pos] = data;
//             engine->state = WAIT_SYNC;
//             engine->pos = 0;
//             break;
//     }
// }

struct app_state {
  struct pt_payload_engine engine_latest;
  bool engine_valid;
  struct pt_payload_chassis chassis_latest;
  bool chassis_valid;
  uint32_t engine_frame_count;
  uint32_t chassis_frame_count;
};

void render(const struct app_state *s) {
  erase();

  if (s->engine_valid) {
    const struct pt_payload_engine *e = &s->engine_latest;
    mvprintw(0, 0, "ENGINE  uptime %.1f s frames %u", e->uptime_ms / 1000.0f,
             s->engine_frame_count);

    mvprintw(2, 0, "V_BAT     %5.2f V", adc_to_v_bat(e->adc_v_cell_2));
    draw_bar(2, 24, 30, adc_to_v_bat(e->adc_v_cell_2), 8.4f);

    mvprintw(3, 0, "V_CELL1   %5.2f V", adc_to_v_cell1(e->adc_v_cell_1));
    draw_bar(3, 24, 30, adc_to_v_cell1(e->adc_v_cell_1), 4.2f);

    mvprintw(4, 0, "V_Q       %5.2f V", adc_to_v_q(e->adc_v_q));
    draw_bar(4, 24, 30, adc_to_v_q(e->adc_v_q), 8.4f);

    mvprintw(6, 0, "I_ESC1    %6.2f A", adc_to_i_esc(e->adc_i_esc_1));
    draw_bar(6, 24, 30, adc_to_i_esc(e->adc_i_esc_1), 30.0f);

    mvprintw(7, 0, "I_ESC2    %6.2f A", adc_to_i_esc(e->adc_i_esc_2));
    draw_bar(7, 24, 30, adc_to_i_esc(e->adc_i_esc_2), 30.0f);

    mvprintw(8, 0, "I_SYS     %6.2f A", adc_to_i_sys(e->adc_i_sys));
    draw_bar(8, 24, 30, adc_to_i_sys(e->adc_i_sys), 5.0f);

    mvprintw(10, 0, "TEMP     %5.1f C", adc_to_temp_c(e->adc_temp));
    draw_bar(10, 24, 30, adc_to_temp_c(e->adc_temp), 100.0f);
    // mvprintw(0, 0, "ENGINE  uptime %.1f s   frames %u",
    //          e->uptime_ms / 1000.0f, s->engine_frame_count);
    // mvprintw(2, 0, "V_BAT     %5.2f V", adc_to_v_bat(e->adc_v_cell_2));
    // draw_bar(2, 24, 30, adc_to_v_bat(e->adc_v_cell_2), 8.4f);
    //  ... 既存表示 ...
  } else {
    mvprintw(0, 0, "ENGINE  waiting...");
  }

  if (s->chassis_valid) {
    const struct pt_payload_chassis *c = &s->chassis_latest;
    mvprintw(13, 0, "CHASSIS uptime %.1f s   frames %u", c->uptime_ms / 1000.0f,
             s->chassis_frame_count);
    mvprintw(14, 0, "  engine_ok=%u  drop=%u  flags=0x%02X",
             c->engine_frames_ok, c->engine_frames_dropped, c->flags);
  } else {
    mvprintw(13, 0, "CHASSIS waiting...");
  }

  refresh();
}

struct keys {
  bool w, a, s, d;
};

float current_throttle_fwd = 0.0f;  // 前後 (-1000..+1000)
float current_throttle_turn = 0.0f; // 左右

const float RAMP_PER_TICK_FWD = 2.5f; // 50Hz × 50 = 2500/s → 0.4s で full
const float RAMP_PER_TICK_TURN = 2.5f;
const float DECAY_PER_TICK = 2.5f; // 解放時の戻り

void compute_target_and_ramp(const struct keys *k, int16_t *out_l,
                             int16_t *out_r) {
  // 目標値
  float target_fwd = 0.0f;
  if (k->w)
    target_fwd += 1000.0f;
  if (k->s)
    target_fwd -= 1000.0f;
  float target_turn = 0.0f;
  if (k->d)
    target_turn += 1000.0f;
  if (k->a)
    target_turn -= 1000.0f;

  // 前後ramp
  float diff_fwd = target_fwd - current_throttle_fwd;
  float step_fwd = (target_fwd != 0.0f) ? RAMP_PER_TICK_FWD : DECAY_PER_TICK;
  if (diff_fwd > step_fwd)
    current_throttle_fwd += step_fwd;
  else if (diff_fwd < -step_fwd)
    current_throttle_fwd -= step_fwd;
  else
    current_throttle_fwd = target_fwd;

  // 旋回 ramp
  float diff_turn = target_turn - current_throttle_turn;
  float step_turn = (target_turn != 0.0f) ? RAMP_PER_TICK_TURN : DECAY_PER_TICK;
  if (diff_turn > step_turn)
    current_throttle_turn += step_turn;
  else if (diff_turn < -step_turn)
    current_throttle_turn -= step_turn;
  else
    current_throttle_turn = target_turn;

  // 戦車差動: 左右 = fwd ± turn
  float l = current_throttle_fwd + current_throttle_turn;
  float r = current_throttle_fwd - current_throttle_turn;

  // クリップ
  if (l > 500.0f)
    l = 500.0f;
  if (l < -500.0f)
    l = -500.0f;
  if (r > 500.0f)
    r = 500.0f;
  if (r < -500.0f)
    r = -500.0f;

  *out_l = (int16_t)l;
  *out_r = (int16_t)r;
}
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

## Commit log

2026-04-04 モーターx1の制御プログラムを試作
2026-04-04 電源モジュールのCAD試作
    [power-module.kicad_pcb, power-module.kicad_sch]
2026-04-04 README.md 部品表の修正
2026-04-11 ESCx1制御のRPi側
2026-04-11 ホストマシンで実行する用にMakefile修正
2026-04-12 コードスタイルの統一
2026-04-12 後退コマンドを追加
2026-04-13 Rename kicad -> pcb
    [power-module.kicad_pcb, power-module.kicad_sch]
2026-05-02 SSAJ120100のフットプリント修正
2026-05-03 pippitank-engine REV_A
    [pippitank-engine-B_Cu.gbl, pippitank-engine-B_Mask.gbs, pippitank-engine-B_Paste.gbp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]
2026-05-03 Remove unused pcb designe
    [power-module.kicad_pcb, power-module.kicad_sch]
2026-05-12 Add ESC adaptor symbol & footprint
2026-05-12 Add pippitank-esc-adaptor rev_a
    [pippitank-esc-adaptor-B_Cu.gbl, pippitank-esc-adaptor-B_Mask.gbs, pippitank-esc-adaptor-B_Paste.gbp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]
2026-05-12 pippitank-engineのエミュレータ作成、protocol.hのcpp移行
2026-07-10 床走行マイルストーンまでのファーム実装
2026-07-10 テレメトリログを追加
    [20260530-2059.csv, 20260530-2105.csv, 20260626-2241.csv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]
2026-07-10 pcb/のgitiginore調整
2026-07-10 pippitank-esc-adaptor rev_b概要を追加
2026-07-10 README.md, CLAUDE.mdを更新
